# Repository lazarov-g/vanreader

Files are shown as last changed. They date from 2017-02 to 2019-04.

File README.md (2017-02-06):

# vanreader
Van Protocol reader 
The source is for atmega328p ( arduino chip), and it's compiled in Atmel Studio ( IDE for atmel products).

These project purpouse is to connect existing Stalk controler on Peugeot 206 with Pioneer headunit, by listening the messages on the VAN network and sending signals to player.

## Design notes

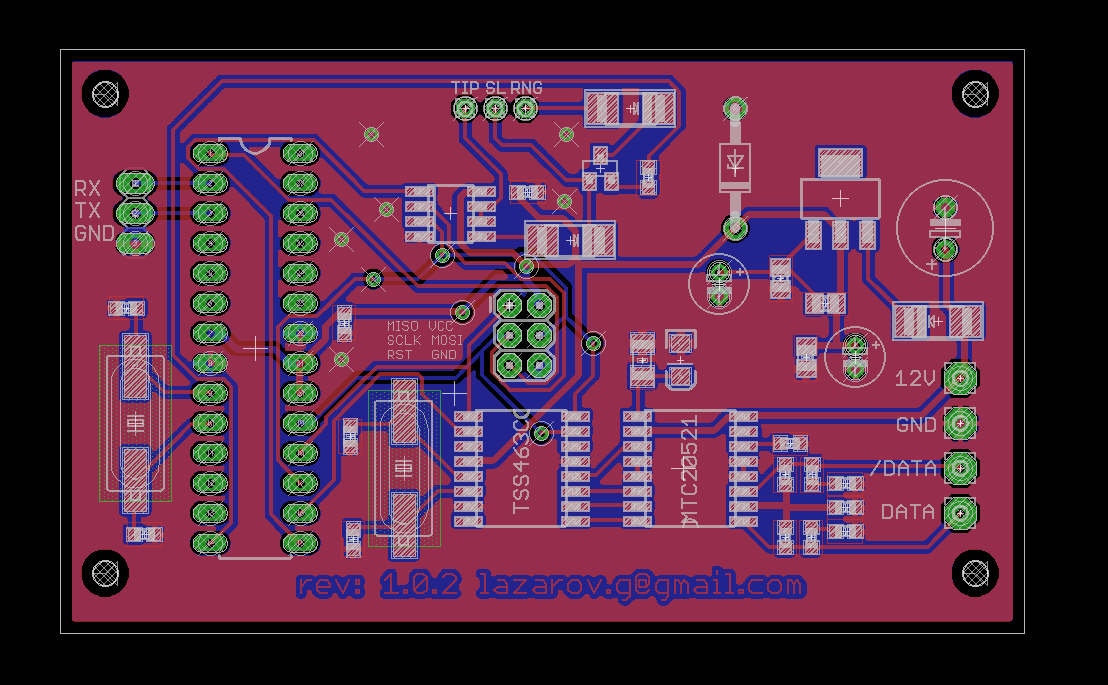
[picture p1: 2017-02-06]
van_board.png

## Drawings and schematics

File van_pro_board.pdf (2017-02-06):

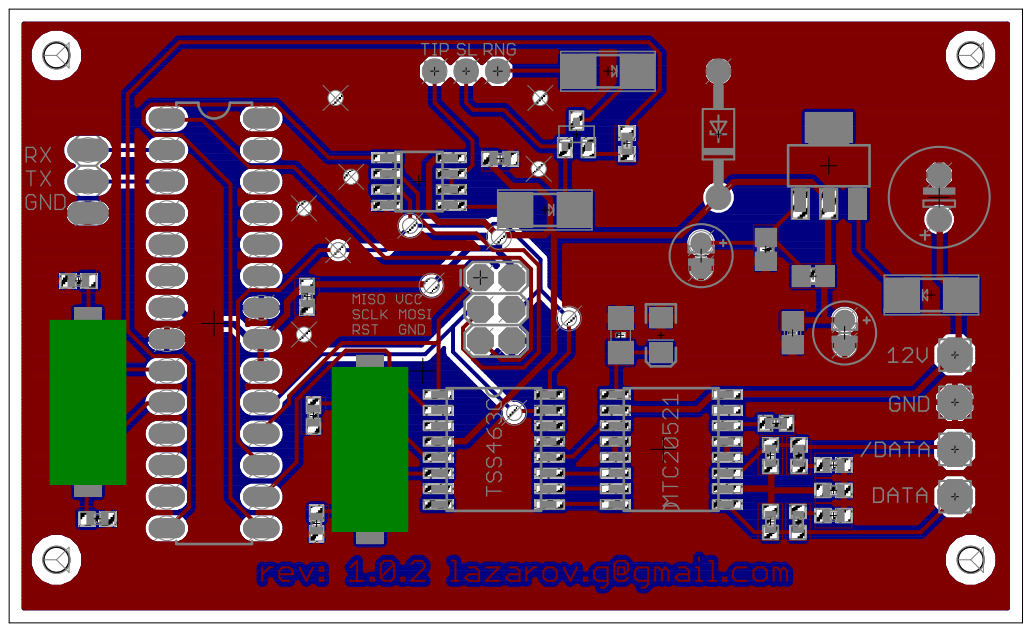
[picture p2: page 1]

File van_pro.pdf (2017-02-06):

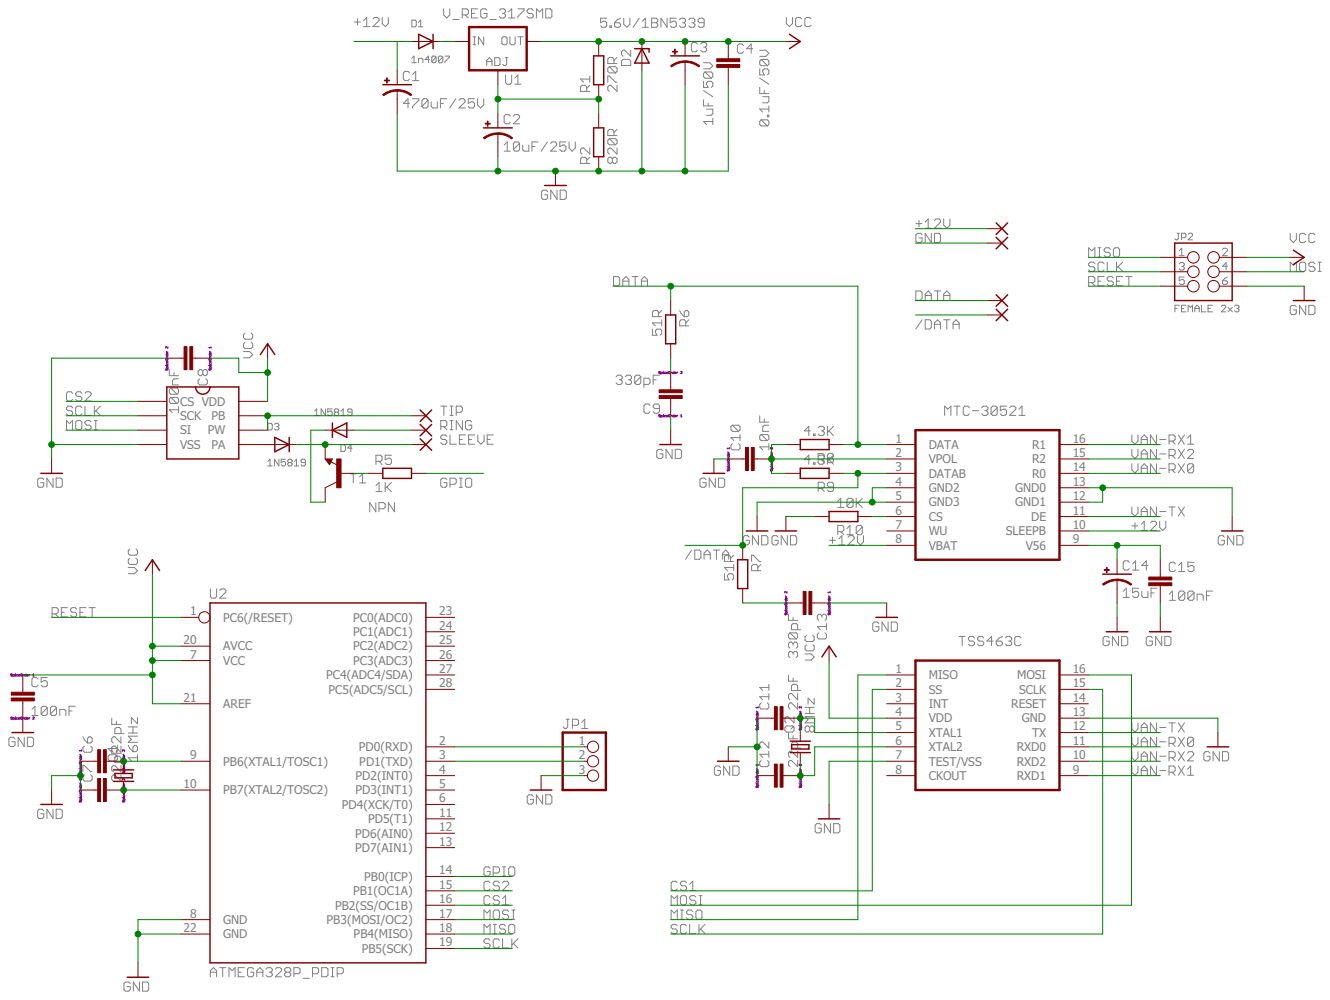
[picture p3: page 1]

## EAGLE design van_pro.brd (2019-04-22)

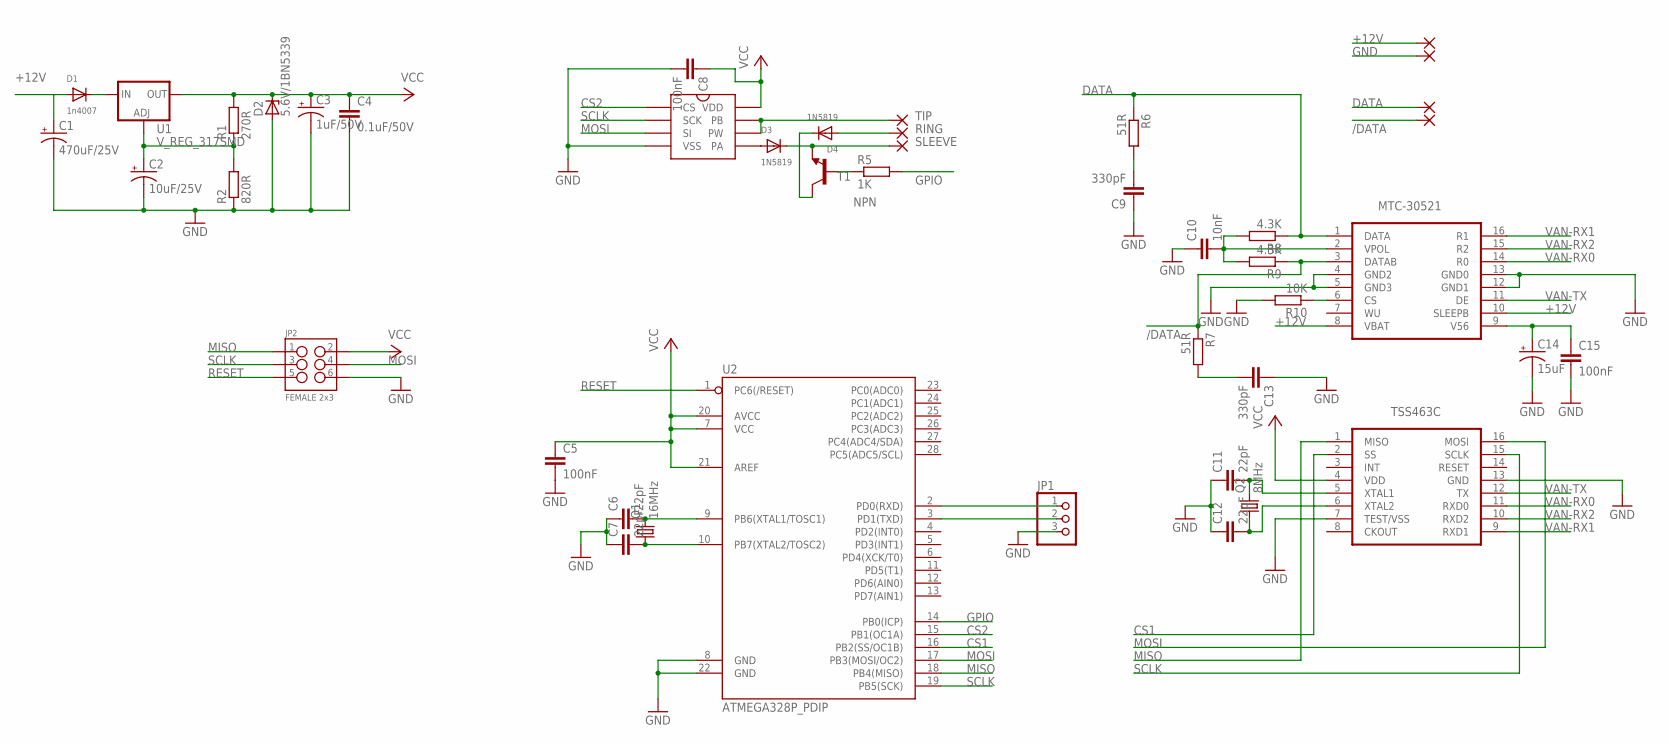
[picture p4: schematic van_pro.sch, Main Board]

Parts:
12V: WIREPAD2,54/0,8; 2,54/0,8
/DATA: WIREPAD2,54/0,8; 2,54/0,8
C1: 470uF/25V; E3,5-8
C2: 10uF/25V; E2-5
C3: 1uF/50V; E2-5
C4: 0.1uF/50V; C0805
C5, C8: 100nF; C0603
C6, C7, C11, C12: 22pF; C0603; MPN 08052A220JAT2A
C9, C13: 330pF; C0603; MPN 08052A220JAT2A
C10: 10nF; C0603; MPN 08052A220JAT2A
C14: 15uF; EIA3216; MPN 08052A220JAT2A
C15: 100nF; C1206; MPN 08052A220JAT2A
D1: 1n4007; SMADIODE
D2: 5.6V/1BN5339; DO41Z10
D3, D4: 1N5819; SMADIODE
DATA: WIREPAD2,54/0,8; 2,54/0,8
GND: WIREPAD2,54/0,8; 2,54/0,8
IC1: MCP41100; SO8
IC2: MTC-20521; MTC-30521
JP1: PINHD-1X3; 1X03
JP2: FEMALE 2x3; 2X3
Q1: 16MHz; HC49UP; MPN HC49SM-3.6864-30-50-60-16-ATF
Q2: 8MHz; HC49UP; MPN HC49SM-3.6864-30-50-60-16-ATF
R1: 270R; R0805
R2: 820R; R0805
R5: 1K; R0603
R6, R7: 51R; R0603
R8, R9: 4.3K; R0603
R10: 10K; R0603
RNG: 1,6/0,8
SL: 1,6/0,8
T1: NPN; SOT23-EBC
TIP: 1,6/0,8
U1: V_REG_317SMD; SOT223
U2: ATMEGA328P_PDIP; DIL28-3
VAN1: TSS463C

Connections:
+12V: 12V.1, C1.+, D1.A, IC2.8 (VBAT), IC2.10 (SLEEPB)
/DATA: /DATA.1, IC2.3 (DATAB), R7.1, R9.1
CS1: U2.16 (PB2(SS/OC1B)), VAN1.2 (SS)
CS2: IC1.1 (CS), U2.15 (PB1(OC1A))
DATA: DATA.1, IC2.1 (DATA), R6.1, R8.1
GND: C1.-, C2.-, C3.-, C4.2, C5.2, C6.1, C7.1, C8.2, C9.1, C10.1, C11.1, C12.1, C13.1, C14.C (-), C15.2, D2.A, GND.1, IC1.4 (VSS), IC2.4 (GND2), IC2.5 (GND3), IC2.12 (GND1), IC2.13 (GND0), JP1.3, JP2.6, R2.1, R10.2, U2.8 (GND), U2.22 (GND), VAN1.7 (TEST/VSS), VAN1.13 (GND)
GPIO: R5.2, U2.14 (PB0(ICP))
MISO: JP2.1, U2.18 (PB4(MISO)), VAN1.1 (MISO)
MOSI: IC1.3 (SI), JP2.4, U2.17 (PB3(MOSI/OC2)), VAN1.16 (MOSI)
unnamed: C11.2, Q2.2, VAN1.5 (XTAL1)
unnamed: D3.A, IC1.5 (PA)
unnamed: D4.C, T1.C
unnamed: C6.2, Q1.2, U2.9 (PB6(XTAL1/TOSC1))
unnamed: C7.2, Q1.1, U2.10 (PB7(XTAL2/TOSC2))
unnamed: R5.1, T1.B
unnamed: C12.2, Q2.1, VAN1.6 (XTAL2)
unnamed: C2.+, R1.1, R2.2, U1.1 (ADJ)
unnamed: D1.C, U1.3 (IN)
unnamed: IC2.6 (CS), R10.1
unnamed: C10.2, IC2.2 (VPOL), R8.2, R9.2
unnamed: C13.2, R7.2
unnamed: C9.2, R6.2
unnamed: C14.A (+), C15.1, IC2.9 (V56)
RESET: JP2.5, U2.1 (PC6(/RESET))
RING: D4.A, RNG.1
RX: JP1.1, U2.2 (PD0(RXD))
SCLK: IC1.2 (SCK), JP2.3, U2.19 (PB5(SCK)), VAN1.15 (SCLK)
SLEEVE: D3.C, SL.1, T1.E
TIP: IC1.6 (PW), IC1.7 (PB), TIP.1
TX: JP1.2, U2.3 (PD1(TXD))
VAN-RX0: IC2.14 (R0), VAN1.11 (RXD0)
VAN-RX1: IC2.16 (R1), VAN1.9 (RXD1)
VAN-RX2: IC2.15 (R2), VAN1.10 (RXD2)
VAN-TX: IC2.11 (DE), VAN1.12 (TX)
VCC: C3.+, C4.1, C5.1, C8.1, D2.C, IC1.8 (VDD), JP2.2, R1.2, U1.2 (OUT), U2.7 (VCC), U2.20 (AVCC), U2.21 (AREF), VAN1.4 (VDD)

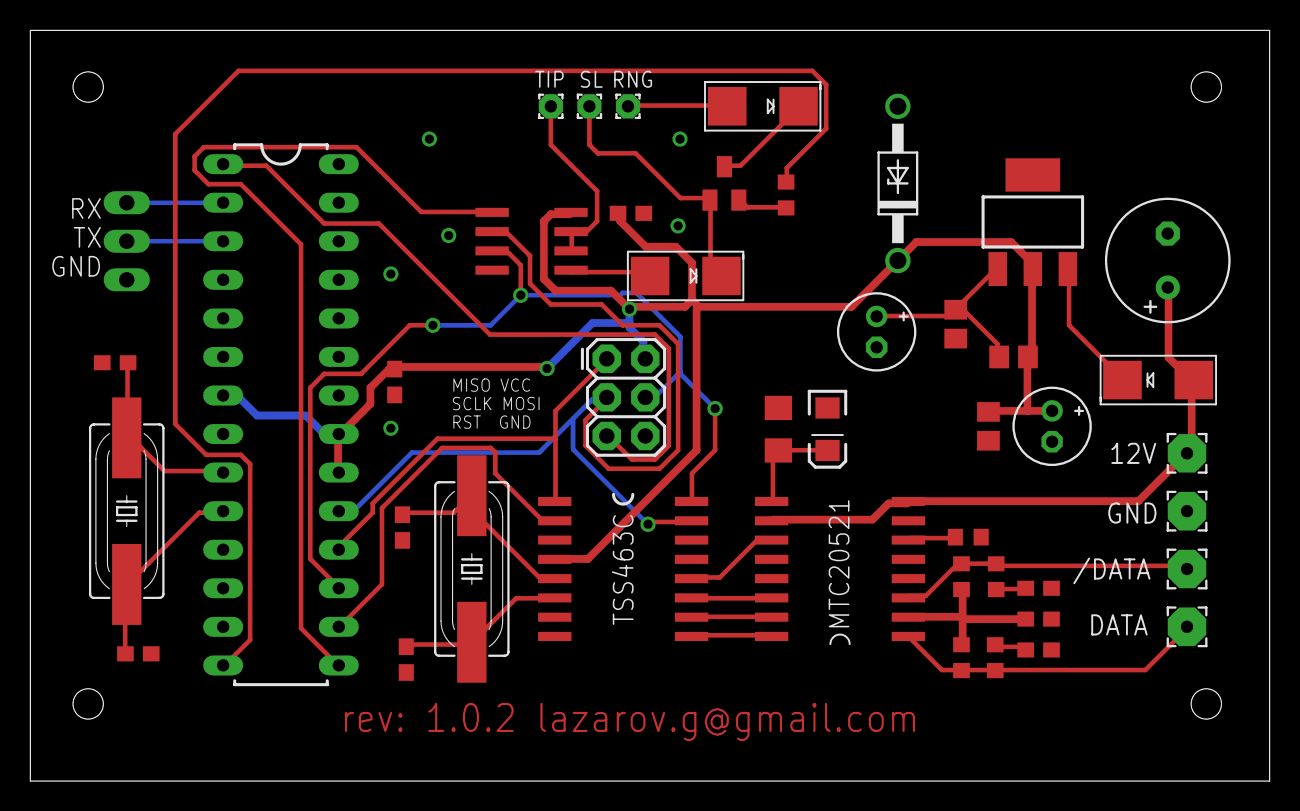
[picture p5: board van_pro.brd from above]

Board: 2 copper layers, 81.6 x 49.5 mm, 44 parts (1 on the bottom side), 35 nets.

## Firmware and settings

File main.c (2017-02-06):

/*
 * VanStalk.c
 *
 * Created: 25.10.2015 20:23:05
 * Author:	George Lazarov
 * email:	lazarov.g@gmail.com
 */ 

#define F_CPU 16000000L

#include <avr/io.h>
#include <util/delay.h>
#include <avr/interrupt.h>

#define ROKE	(1)
#define RNOKE	(0)

#define MOTOROLA_MODE   0x00
#define WRITE           0xE0
#define READ            0x60
#define ADDR_ANSW       0xAA
#define CMD_ANSW        0x55

#define LINECONTROL  0x00      // r/w - 0x00
#define TRANSMITCTR  0x01      // r/w - 0x02
#define DIAGNCTRL    0x02      // r/w - 0x00
#define COMMANDREG   0x03      // w   - 0x00
#define LINESTAT     0x04      // r   - 0bx01xxx00
#define TRANSTAT     0x05      // r   - 0x00
#define LASTMSGSTAT  0x06      // r   - 0x00
#define LASTERRSTAT  0x07      // r   - 0x00
#define INTSTATUS    0x09      // r   - 0x80
#define INTENABLE    0x0A      // r/w - 0x80
#define INTRESET     0x0B      // w

// Channels
#define CHANNEL_ADDR( x)	( 0x10 + ( 0x08 * x))
#define CHANNELS     14
// Mailbox - data register
#define GETMAIL( x)         ( 0x80 + x)

// Buttons
/*   7  6  5  4  3  2  1  0   */
/*  su sd wu wd vu  vd sr ?   */
#define SRC   1
#define VDWN  2
#define VUP   3
#define WDWN  4
#define WUP   5
#define SDWN  6
#define SUP   7
#define CMD_WAIT_MS	(50)

typedef unsigned char byte;

// Resistance references for MCP4100
const byte source = 0xfd;      //  1.20 k
const byte att    = 0xf8;      //  3.50 k
const byte displ  = 0xf1;      //  5.75 k
const byte tup    = 0xeb;      //  8.00 k
const byte tdwn   = 0xe2;      // 11.25 k
const byte volup  = 0xd5;      // 16.00 k
const byte voldwn = 0xbe;      // 24.00 k
const byte band   = 0x4d;      // 62.75 k
const byte nocmd  = 0x00;      // max

// Global variables
volatile int error   = 0x00;   // TSS463C out of sync error
volatile byte interr = 0x00;

// Button states
volatile byte oldwheel   = 0x80;
volatile byte wheel      = 0x80;
volatile byte button     = 0x00;
volatile byte wuloop     = 0x00;
volatile byte wdwnloop   = 0x00;

// Functions declaration
byte spi_transfer( volatile byte data);
void tss_init();
void execCmd( const byte cmd);
void register_set( byte address, byte value);
byte register_get( byte address);
void motorolla_mode();

void setup()
{
	TIMSK0 = 0;
	DDRB |= (1 << DDB3) | (1 << DDB5) | (1 << DDB2) | (1 << DDB1) | ( 1 << DDB0);
	
	PORTB |= ( 0 << PINB0);
	PORTB |= ( 1 << PINB2);
	SPCR = (1 << SPE) | (1 << MSTR) | (1 << CPOL) | (1 << CPHA);
	byte clr = SPSR;
	clr = SPDR;
	(void)clr;
	//_delay_ms( 10);
	
	// Enable ATMega Interrupts on INT0
	EICRA |= (1 << ISC01); // The falling edge of INT0 generates an interrupt request
	EIMSK |= (1 << INT0);  // Enable INT0
	tss_init();
};

void tss_init()
{
	motorolla_mode();
	_delay_ms( 10);

	// disable all channels
	for ( int i = 0 ; i < CHANNELS ; i++)
	{
		register_set( CHANNEL_ADDR( i) + 3, 0x0F);
		_delay_ms( 10);
	}

	// set Channel 0 to receive messages from ID 9C4
	// and receive data in address 0x80
	/*
		ID_MASK         0x07 ID_M [3:0] x x x x
		ID_MASK         0x06 ID_M [11:4]
		(No register)   0x05 x x x x x x x x
		(No register)   0x04 x x x x x x x x
		MESS_L/STA      0x03 M_L [4:0] CHER CHTx CHRx
		MESS_PTR        0x02 DRACK M_P [6:0]
		ID_TAG/CMD      0x01 ID_T [3: 0] EXT RAK RNW RTR
		ID_TAG          0x00 ID_T [11:4]
	*/
	register_set( CHANNEL_ADDR( 0) + 0, 0x9C); //  ID_TAG 9C4 - Radio Control
	register_set( CHANNEL_ADDR( 0) + 1, 0x41); //  ID_TAG, RNW = 0, RTR = 1
	register_set( CHANNEL_ADDR( 0) + 2, 0x00); //  MESS_PTR 0 ( 0x80 + 0) - MAILBOX ADDRESS
	register_set( CHANNEL_ADDR( 0) + 3, 0xf8); //  M_L [4:0] = 0x1F Frame with 30 DATA bytes , CHER = 0, CHTx = 0, CHRx = 0
	register_set( CHANNEL_ADDR( 0) + 6, 0x9C); //  ID_MASK 9C4
	register_set( CHANNEL_ADDR( 0) + 7, 0x40); //  ID_MASK 

	register_set( LINECONTROL, 0x20); // Clock Divider 0010 - 0x02 ( TSCLK = XTAL1 / n * 16) or ( TSCLK = 16000000 / 2 * 16) or 500000
	_delay_ms( 10);
	register_set( TRANSMITCTR, 0x32); // MT: 0011 ( Maximum Retries = 0x03) VER 001 fixed
	_delay_ms( 10);
	
	// Enable TSS Interrupts
	byte intEnable = 0x80; // Default value reset: 1xx0 0000
	intEnable |= ( 1 << ROKE) | ( 1 << ROKE);
	register_set( INTENABLE, intEnable);
	_delay_ms( 10);
	
	register_set( COMMANDREG, 0x10);  // ACTI - activate line
	_delay_ms( 10);
	error = 0;
};

void execCmd( const byte cmd)
{
	PORTB &= ~( 1 << PINB1);
	spi_transfer( 0x11);
	spi_transfer( cmd);
	PORTB |= ( 1 << PINB1);
	_delay_ms( CMD_WAIT_MS);
	PORTB &= ~( 1 << PINB1);
	spi_transfer( 0x11);
	spi_transfer( nocmd);
	PORTB |= ( 1 << PINB1);
};

void register_set( byte address, byte value)
{
	byte res = 0;

	PORTB &= ~( 1 << PINB2);

	_delay_ms( 4);
	res = spi_transfer( address);
	if ( res != ADDR_ANSW)
		error++;
	_delay_ms( 8);
	res = spi_transfer( WRITE);
	if ( res != CMD_ANSW)
		error++;
	_delay_ms( 15);
	spi_transfer( value);
	_delay_ms( 12);

	PORTB |= ( 1 << PINB2);
};

byte register_get( byte address)
{
	byte value = 0;

	PORTB &= ~( 1 << PINB2);

	_delay_ms( 4);
	value = spi_transfer( address);
	if ( value != ADDR_ANSW)
		error++;
	_delay_ms( 8);
	value = spi_transfer( READ);
	if ( value != CMD_ANSW)
		error++;
	_delay_ms( 15);
	value = spi_transfer( 0xff);
	_delay_ms( 12);

	PORTB |= ( 1 << PINB2);

	return value;
};

void motorolla_mode()
{
	byte value;

	PORTB &= ~( 1 << PINB2);

	_delay_ms( 4);
	value = spi_transfer( MOTOROLA_MODE);
	if ( value != ADDR_ANSW)
		error++;
	_delay_ms( 8);
	value = spi_transfer( MOTOROLA_MODE);
	if ( value != CMD_ANSW)
		error++;
	_delay_ms( 12);

	PORTB |= ( 1 << PINB2);
};

byte spi_transfer( volatile byte data)
{
	byte res;

	SPDR = data;
	while (!(SPSR & (1 << SPIF))) {};
	res = SPDR;

	return res;
};

int main(void)
{
	setup();
	sei();
	
	while (1)
	{
		if( !error) {
			
			button  = register_get( GETMAIL( 1));
			wheel   = register_get( GETMAIL( 2));

			if( wheel > oldwheel || wuloop != ( button & ( 1 << WUP))) {
				wuloop = ( button & ( 1 << WUP));
				oldwheel = wheel;
				PORTB |= ( 1 << PINB0);
				execCmd( tup);
				PORTB &= ~( 1 << PINB0);
			}
			else if( wheel < oldwheel || wdwnloop != ( button & ( 1 << WDWN))) {
				wdwnloop = ( button & ( 1 << WDWN));
				oldwheel = wheel;
				PORTB |= ( 1 << PINB0);
				execCmd( tdwn);
				PORTB &= ~( 1 << PINB0);
			}
			else if ( button & ( 1 << SRC)) {
				execCmd( source);
			}
			else if ( ( button & ( 1 << VUP)) && ( button & ( 1 << VDWN))) {
				execCmd( att);
			}
			else if ( button & ( 1 << VDWN)) {
				execCmd( voldwn);
			}
			else if ( button & ( 1 << VUP)) {
				execCmd( volup);
			}
			else if ( button & ( 1 << SDWN)) {
				execCmd( tdwn);
			}
			else if ( button & ( 1 << SUP)) {
				execCmd( tup);
			}
			
			register_set( CHANNEL_ADDR( 0) + 3, 0xf8);
		}
		else {
			tss_init();
		}
		_delay_ms(10);
	}
};

ISR(INT0_vect)
{
	//interr = register_get( INTSTATUS);
	//if( interr & ( 1 << ROKR) && interr & ( 1 << RNOKR))
	//register_set( INTRESET, 0x83);
	//inter |= ( 1 << 1) | (1 << 0);
	//register_set( INTRESET, 0x00);
};

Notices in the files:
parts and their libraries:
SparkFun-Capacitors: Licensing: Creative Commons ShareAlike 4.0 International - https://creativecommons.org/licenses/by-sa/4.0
